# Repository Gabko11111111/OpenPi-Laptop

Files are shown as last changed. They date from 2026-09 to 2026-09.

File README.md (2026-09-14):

# OpenPi Laptop — v0.3 budget prototype

A Raspberry Pi 5 **4 GB** mini laptop with **64 GB microSD**, a **5-inch HDMI display**, a small wireless keyboard with touchpad, and a custom PETG case. The keyboard is retained with screws accessed from underneath. No magnets. The computer uses wall power; only the intact purchased keyboard has its own factory battery.

**Planning total: EUR 250.00 including allowances for delivery and small parts. This is not a confirmed shopping-cart total. Funding, component fit, display touch input and physical tests are not approved or proven.** See the remaining purchasing checks before submitting or ordering.

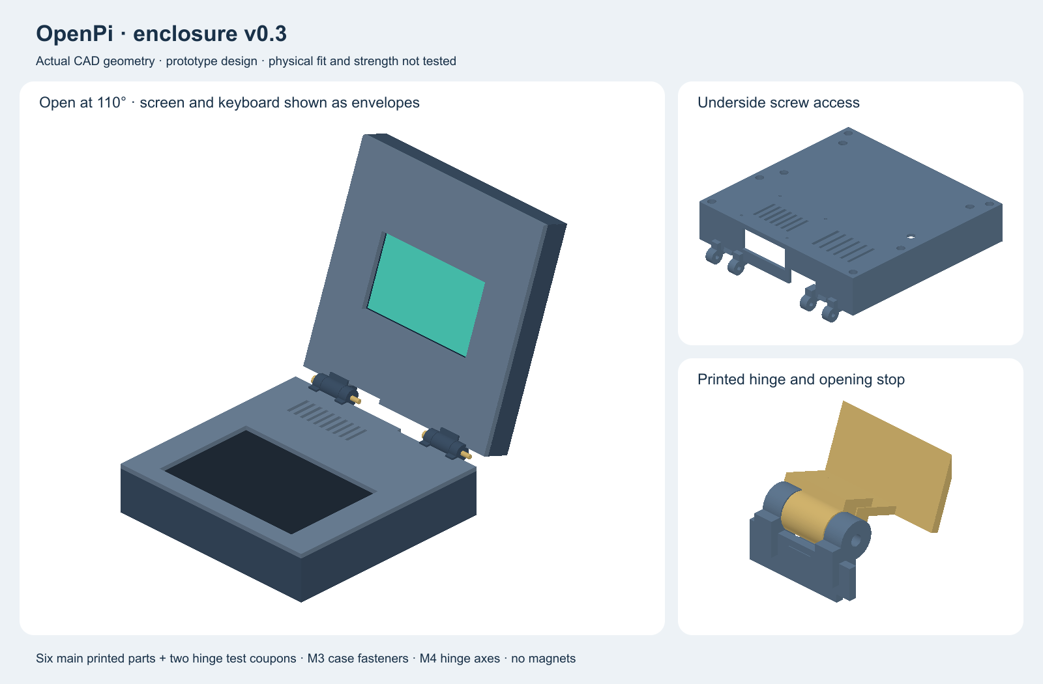
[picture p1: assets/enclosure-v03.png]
Actual v0.3 CAD geometry


The image is rendered from the CAD. Screen and keyboard are simplified reference boxes, not exact product surfaces. The earlier appearance concept and v0.2 assets are historical and are not the current shopping design.

[Stardance project](https://stardance.hackclub.com/projects/61671) · [BOM.csv](BOM.csv) · [Download project ZIP](OpenPi-project-files.zip) · [CAD folder](CAD/v0.3) · [Budget evidence](docs/budget.md)

## What changed to reduce cost

- Keep the requested Pi 5 4 GB, 64 GB storage, proper 27 W power supply and Active Cooler.
- Replace the 7-inch DSI display with the 5-inch HDMI panel, Elecom code 17259. Use the keyboard touchpad; Pi 5 touch drivers are not validated.
- Replace the Perixx keyboard with the small PROLECH/BLOW KS-6 candidate, Pabex code 84-256-. Verify the exact variant and package before ordering.
- Shrink the main case body from 262 × 250 mm to **196 × 190 mm** and resize the keyboard opening, rails, display cradle and bezel. Keep underside screws and printed friction hinges.
- Budget a light-green PETG spool rather than requiring charcoal. Render colors are illustrative.

## Funding and the complete budget

- Target request: **S tier, USD 200 maximum**, subject to reviewer approval.
- Total spending ceiling: **EUR 250**, including delivery, VAT and payment charges.
- At the previously recorded reference rate of EUR 1 = USD 1.1592, USD 200 is approximately EUR 172.53. The expected contribution is approximately **EUR 77.47**, not EUR 50. The builder accepted the EUR 250 plan after this difference was explained.
- These conversion figures are illustrative, not a live grant-card conversion quote. Confirm the actual usable grant and personal contribution before ordering. A lower grant does not authorize a larger personal contribution automatically.
- No grant request or purchase has been submitted by this revision.

## Itemized estimate

| Part | EUR | Evidence |
|---|---:|---|
| Raspberry Pi 5 | 129.90 | Observed retailer price |
| Elecom HDMI LCD code 17259 | 29.99 | Live browser price; 9 in stock |
| PROLECH / BLOW mini KS-6; code 84-256- | 7.39 | Live browser sale price; in stock |
| Goodram M1AA 64 GB | 16.39 | Live browser price; delivery up to 7 days |
| Official Raspberry Pi 27 W USB-C supply | 12.95 | Observed retailer price |
| Official Raspberry Pi 5 Active Cooler | 6.50 | Live browser price; in stock |
| 3DPower Basic PETG Light Green | 13.90 | Search listing reference; live verification pending |
| Enclosure v0.3 fastener set | 10.00 | Unverified purchasing allowance |
| Integral printed hinges | 0.00 | Included elsewhere |
| Display cables | 6.00 | Unverified purchasing allowance |
| Pads and feet | 1.00 | Unverified purchasing allowance |
| USB microSDXC reader | 3.00 | Unverified purchasing allowance |
| Delivery | 12.00 | Unverified combined allowance |
| Reserve | 0.98 | Planning reserve |
| **Planning total** | **250.00** | **Includes estimates; not a delivered quote** |

This replaces the earlier EUR 222 / EUR 50 plan. **No price has been reduced just to match the target:** quoted products and unquoted allowances are labeled separately. The EUR 10 fastener allowance, EUR 12 total delivery allowance and EUR 0.98 reserve are especially tight. Final checkout may exceed this plan; in that case do not buy or submit an inaccurate bill.

## Connections

v0.3 connection overview

The Pi supply powers the computer through USB-C. Video goes from a Pi micro-HDMI port to the display HDMI input. A separate USB lead powers the display through its verified power input; confirm that connector with the seller. The keyboard uses its included wireless USB receiver; its charging cable does not imply USB keyboard data. The cooler uses the Pi fan socket. No laptop battery or DSI ribbon is part of this revision.

## Before ordering

Confirm all package contents, stock, final shipping, cable lengths, display power input and keyboard dimensions. Quote full packs of fasteners and pads. The displayed core prices were checked on 13 September 2026, but the filament quote and all allowances remain unverified. **The plan is not funding-ready until these gaps are resolved.** Basic tools and a card-writing computer must be available or borrowed.

## Step-by-step build

No physical build has been completed. Work in this order; record only your own real work in Lapse and explain AI assistance honestly in Stardance.

1. **Confirm procurement.** Follow the budget checks first. Do not buy the original 7-inch display or Perixx keyboard for this revision. Check all prices including shipping and the actual grant conversion.
2. **Measure the parts.** Record the keyboard body, sturdy outer lip, keys, touchpad, charging port, power switch and battery-cover access. Record the display PCB, glass, connectors, active area and safe support borders. Adjust CAD before a full print. The current keyboard envelope is only a provisional 146.8 × 97.5 × 19 mm box. Curved corners and buttons are not modeled.
3. **Prepare the card.** On an existing computer, use the official Raspberry Pi Imager to write the current recommended Raspberry Pi OS for Pi 5 to the 64 GB card. Select the correct card carefully: writing erases that card. Keep passwords out of recordings. Safely eject after verification.
4. **Bench-test without the enclosure.** With all power disconnected, fit the official Active Cooler using its instructions, insert the card, connect the display by micro-HDMI-to-HDMI cable, connect its verified 5 V USB power input, and insert the keyboard USB receiver. Keep boards on an insulating surface. Charge the keyboard using its factory lead and manual. Connect the official 27 W supply to the Pi last.
5. **Check basic operation.** Confirm boot, HDMI image at the supported 800 × 480 mode, typing, pointer movement and cooling. If the display has no image, test the Pi with a known monitor and consult current official Raspberry Pi display configuration documentation. Do not run old vendor driver scripts blindly. Touchscreen operation is not promised; the keyboard touchpad is the intended pointer.
6. **Power off properly.** Shut down the operating system, wait for shutdown, then disconnect wall power before moving connectors or installing screws.
7. **Print tests first.** Print both hinge coupons and small fit sections of the keyboard opening and display cradle. Check all screws and nut pockets. Update the nominal model until real parts fit without bending.
8. **Slice all parts.** Use calibrated PETG settings, initially 0.2 mm layers and four walls, with solid local hinge reinforcement. Check support removal and the total filament mass including coupons. Keep the full purchase and print plan within the budget.
9. **Assemble.** Follow the exact screw list and detailed assembly document below. Protect display PCB and glass with nonconductive supports. Retain the keyboard from underneath without crushing its factory battery. Keep charging and power controls accessible.
10. **Route cables.** Use separate HDMI and USB power leads with gentle service loops. Keep them out of the fan and hinge teeth. Never power the display from two sources simultaneously. No DSI ribbon is used in v0.3.
11. **Test the finished prototype.** Check boot, keyboard, pointer, fan clearance and thermal throttling under a modest workload. Slowly open and close the lid while watching cables. Record actual results, photos and any failed tests. Do not claim unperformed tests.
12. **Document and submit.** Update the BOM with final quoted prices, keep real devlogs, and let Stardance assess the appropriate tier. No tier or grant is guaranteed. A design request is not proof that the laptop is already built.

[Exact assembly and fasteners](CAD/v0.3/ASSEMBLY.md) · [Budget](docs/budget.md) · [Raspberry Pi documentation](https://www.raspberrypi.com/documentation/computers/getting-started.html)

## CAD downloads

- [Editable assembly](CAD/v0.3/openpi-assembly.FCStd) and [editable parts](CAD/v0.3/openpi-parts.FCStd).
- [Assembly STEP](CAD/v0.3/openpi-assembly.step) and [parts STEP](CAD/v0.3/openpi-parts.step).
- [CAD generator](CAD/build_enclosure.py) and [geometry check results](CAD/v0.3/checks.json).
- [base](CAD/v0.3/STL/base.stl).
- [keyboard_deck](CAD/v0.3/STL/keyboard_deck.stl).
- [keyboard_rail_left](CAD/v0.3/STL/keyboard_rail_left.stl).
- [keyboard_rail_right](CAD/v0.3/STL/keyboard_rail_right.stl).
- [lid_back](CAD/v0.3/STL/lid_back.stl).
- [display_bezel](CAD/v0.3/STL/display_bezel.stl).
- [hinge_fixed_coupon](CAD/v0.3/STL/hinge_fixed_coupon.stl).
- [hinge_moving_coupon](CAD/v0.3/STL/hinge_moving_coupon.stl).

## Full assembly instructions and exact screws

This is a designed prototype with printable geometry. Its fit, strength, hinge friction, and cable life have not been physically verified. Start with the two hinge coupons, not a complete case print.

## Files and dimensions

- `openpi-assembly.FCStd`: assembled model with the lid open at 110 degrees. Keyboard, Pi board, and screen objects are simplified reference envelopes.
- `openpi-parts.FCStd`: six individual manufactured parts in design coordinates.
- `openpi-assembly.step` and `openpi-parts.step`: neutral CAD exports.
- `STL/`: six main printable parts, one fixed hinge coupon, and one moving hinge coupon. Each STL is translated to its own origin; these are not prearranged slicer plates.
- `../build_enclosure.py`: editable parameterized geometry source; regenerate using FreeCAD 1.1.1 Python.
- `checks.json`: recorded geometric and mesh checks.

The base body is 196 × 190 mm; its integral hinge barrels extend depth to 202 mm. The lid back is 196 × 206 mm including its moving hinge tabs. The main base/deck top is 43 mm high. The closed lid is separated from it by 3 mm, and the back of the lid is at 73 mm. Hinge axes are at y=195, z=44.5 in base coordinates. Small added foot pads are outside these dimensions.

The parts fit inside the stated QIDI Q2 270 × 270 × 256 mm volume as geometric envelopes. The deepest part is 206 mm, leaving room for a reasonable brim on a 270 mm bed. Any brim, support, skirt, or printer exclusion must fit too. Check this in the slicer; do not assume the printer can use every nominal millimetre.

## Exact screw shopping list for this revision

All lengths below are measured **under the head**, except nuts and spacers. Choose metric machine screws, not wood screws or self-tapping screws. Stainless A2 is suitable. The counts are quantities actually used; optional spares are separate.

| Item | Used | Application |
|---|---:|---|
| **M3 × 12 mm**, 0.5 mm pitch, ISO 4762 / DIN 912 socket-head screw | **12** | 6 base-to-deck joints + 6 lid-back-to-bezel joints |
| **M3 × 8 mm**, 0.5 mm pitch, ISO 4762 / DIN 912 socket-head screw | **4** | 2 screws per keyboard support rail, accessed from the underside |
| **M4 × 45 mm**, 0.7 mm pitch, ISO 4762 / DIN 912 socket-head screw | **2** | One metal axis per printed hinge |
| **M2.5 × 6 mm**, 0.45 mm pitch, ISO 4762 / DIN 912 socket-head screw | **4** | Through base floor into bottom of Pi spacers |
| **M2.5 × 5 mm**, 0.45 mm pitch, ISO 4762 / DIN 912 socket-head screw | **4** | Through Pi board and washer into top of spacers |
| **M3 hex nut**, DIN 934, 5.5 mm across flats, nominal 2.4 mm high | **16** | 12 shell joints + 4 keyboard-post pockets |
| **M4 nylon-insert locknut**, DIN 985, 7 mm across flats, nominal 5 mm high | **2** | Hinge friction adjustment and axis retention |
| **M3 flat washer**, 3.2 mm ID × 7 mm OD × 0.5 mm | **16** | Under every M3 screw head |
| **M4 flat washer**, 4.3 mm ID × 9 mm OD × 0.8 mm | **4** | Outside the two hinge forks |
| **Fibre friction washer**, 4.3 mm ID × 10 mm OD × 0.5 mm | **4** | Two per hinge, between printed knuckles |
| **M2.5 nylon flat washer**, 2.7 mm ID × 6 mm OD × 0.5 mm | **8** | Four under board screws, four under floor screw heads |
| **M2.5 female–female nylon spacer, 6 mm long**, continuous through-thread, max 5 mm across flats | **4** | Pi mounting, 6 mm above the 3 mm floor |

Total: **26 screws, 18 nuts, 32 washers, 4 spacers**. Suggested spares: two of each screw size, two M3 nuts, and two M3 washers. Spares are not included in the installed counts. Do not substitute a blind-thread spacer: the opposing screw ends require the specified continuous thread.

Tools: 2 mm, 2.5 mm, and 3 mm hex keys; 7 mm spanner for M4 locknuts; calipers; deburring tool. The built-in cooler uses its supplied fasteners. Display package screws are not required by this cradle design; do not drive any new screw into the glass, display PCB, or keyboard.

## Screw-length checks built into the design

| Joint | Designed stack and tip clearance |
|---|---|
| Base/deck M3 × 12 | Driver-well shoulder z=30.5; 0.5 mm washer places under-head plane z=30. Tip z=42. Nut seated at z=39.2–41.6; blind bore ends z=42.5; deck top z=43. |
| Lid/bezel M3 × 12 | Shoulder z=13.5; washer gives under-head plane z=13. Tip z=25. Nut z=22.2–24.6; bore ends z=26; front z=27. |
| Keyboard M3 × 8 | Rail bottom z=16; washer gives under-head plane z=15.5. Tip z=23.5. Nut z=19.2–21.6; bore ends z=24.5. Screw axes lie outside the keyboard envelope. |
| Pi M2.5 × 6 and × 5 | Bottom screw engages 2.5 mm above the floor. Top screw engages about 2.9 mm assuming 1.6 mm PCB + 0.5 mm washer. Opposing tips have nominal 0.6 mm clearance. Verify actual thickness and spacer thread before tightening. |
| Hinge M4 × 45 | 36 mm knuckle/inner-washer stack + 1.6 mm outer washers + 5 mm nut = 42.6 mm. A 45 mm screw projects nominally 2.4 mm beyond the nut. Confirm the thread reaches the nylon ring; do not replace with a 40 mm screw. |

These are nominal geometric stacks, not manufacturing-tolerance guarantees. Nut-pocket AF is 5.8 mm; M3 clearance bores are 3.4 mm; hinge bores are 4.4 mm; driver wells are 8.2 mm. Printed holes may need careful deburring. If a screw bottoms before clamping, stop and correct the fit.

## Keyboard retention

1. Print the deck and rails only after measuring the exact keyboard's plastic rim, keys, and cable exit. The current envelope is 146.8 × 97.5 × 19 mm, positioned x=24.6–171.4, y=14–111.5, z=20–39. The top opening is 142.8 × 93.5 mm and assumes a usable 2 mm peripheral housing lip. Confirm that this lip does not cover keys or touchpad controls.
2. Fit the four M3 nuts into the underside post pockets. Fit the six shell-joint nuts into the underside deck pockets. A small piece of tape can temporarily retain nuts; keep adhesive off threads.
3. Insert the intact keyboard from below. Attach 1 mm soft pad strips only under its sturdy outer housing edges, above the two rails. Keep pads clear of electronics and moving controls.
4. Attach the two rails using four M3 × 8 screws and washers. The rails touch post shoulders at z=19: this is a hard tightening stop. Tighten gently until seated, never until the keyboard housing bends.
5. A thinner keyboard needs measured rigid shims under its rim, not extreme screw tightening or a large soft foam stack. The current envelope is a provisional KS-6 sizing assumption, not a measurement of the purchased unit; update support height and lip after measuring its rim. Keycap height alone is not sufficient.
6. With the base installed, the four rail screws remain accessible through underside driver holes. Removing the keyboard requires undoing the base/deck fasteners and rails, then withdrawing it from below. It does not lift out from the top.

## Pi and cable assembly

1. With power disconnected, install four 6 mm nylon spacers using the four M2.5 × 6 floor screws and nylon washers.
2. Place the Pi on the spacers, USB/Ethernet edge toward the left service opening, USB-C edge toward the rear opening. Use the four M2.5 × 5 top screws and nylon washers. Stop if the washer contacts a component rather than the board's mounting land.
3. The hole pitch is 58 × 49 mm, based on the [Pi 5 reference drawing](https://datasheets.raspberrypi.com/rpi5/raspberry-pi-5-mechanical-drawing.pdf). The manufacturer itself requires physical-component verification before production. The cooler and all plugged-in cable envelopes still need a physical clearance check.
4. Plug the wireless receiver into USB-A and leave the keyboard charging socket and power switch accessible. Retain the intact keyboard and its factory battery; do not wire its battery to the Pi. Use its included charging lead according to its manual. The generous service openings are intentional prototype features; verify plug insertion before refining them.
5. Route the micro-HDMI/HDMI video cable and USB display power cable through the central rear openings in both shells. Use soft edge protection and strain relief, leaving a service loop. Cables are not included in the rigid-body collision simulation.

## Lid and hinges

1. Test the **fixed and moving hinge coupons** first with one M4 × 45 screw, two outer steel washers, two inner fibre washers, and one M4 locknut. These coupons reproduce the real geometry.
2. Install display support pads against sturdy rear structural surfaces, avoiding electronics and ribbon connectors. The CAD reserves a 120 × 75 × 16 mm display envelope at z=4–20. The seller lists an 8 mm body; connector protrusions and pad stack are unverified. Use measured nonconductive supports under structural borders, not exposed solder joints. Confirm the physical module and its connector protrusions before closing the lid.
3. The bezel opening is 112 × 64 mm, based on a provisional centered 110.7 × 62.3 mm viewing area. Centering is assumed; check the actual active-area location. Never load the active glass or force a bowed panel into position.
4. Fit six M3 nuts to bezel pockets. Attach bezel to lid back with six M3 × 12 screws and washers from the rear. Printed columns limit closure; the padding should retain the display without bending it. Change pad thickness or CAD if the module stack differs.
5. Assemble each hinge along the axis in this order: **M4 screw head → steel washer → fixed knuckle → fibre washer → moving knuckle → fibre washer → fixed knuckle → steel washer → M4 locknut**.
6. Tighten the locknut only enough to remove play and obtain modest friction. The printed stops meet at 110 degrees. Do not force the lid beyond the stop. PETG may creep under sustained clamp load; holding torque and durability require real tests. No numerical tightening torque is claimed.
7. Attach the deck/base with six M3 × 12 screws and washers through the deep underside wells. Apply four feet at least 4 mm thick so the Pi floor screw heads clear the table; keep feet away from vents.
8. Slowly open and close the unpowered lid while watching the cables. Then test the electronics and record results using the build guide. The 110-degree stop is not proof of cable suitability or long-term strength.

## Printing order

1. Print the two hinge coupons first, using PETG, and check the 4.4 mm axis bore and 0.5 mm washer gaps.
2. Check nut capture, rail fit, keyboard lip, display thickness, and the actual board against the design before printing all six large parts. Make local test cuts of those regions in the slicer if needed.
3. Base: floor on bed; use local supports for hinge overhangs, with access for removal. Lid back: outer back on bed; support hinge overhangs. Deck: rotate so its flat top is on the bed and posts grow upward. Bezel: front face on bed. Rails: broad face on bed.
4. Start with a calibrated PETG profile, 0.2 mm layers and at least four perimeters; use solid local infill around hinge roots. These are starting settings, not a strength certification. Inspect layer bonding and hinge-axis alignment on the coupons.
5. Check slicer bounds before adding a brim. The lid is 206 mm deep. Verify brim, skirt and supports in the slicer.

## Automated checks completed

Six main parts exported as valid single solids and closed STL meshes. Bounding boxes fit the nominal printer volume. Named static printed parts and the simplified Pi/keyboard envelopes do not intersect. The rigid printed lid has no detected intersection at the eleven sampled positions from 0 to 110 degrees; a 112-degree check contacts the stop. The test samples angles; it is not a continuous-motion or finite-element analysis. Physical assembly, clamp pressure, cable movement, thermals, and hinge life remain untested.

## Budget and readiness

This is the EUR 250 planning revision. The same exact screw list is retained, with an unquoted EUR 10 purchasing allowance. No physical fit is certified. Display touch input is not part of the validated plan: use HDMI video and the keyboard touchpad. Seller confirmation of display power and keyboard dimensions is required before purchase or full printing.

## AI assistance and honest status

ChatGPT/Codex helped with sourcing, budgeting, documentation, the earlier concept image, parametric CAD and uploads. The builder must understand, measure, adapt, print, assemble and test the hardware. No recorded AI execution time is being presented as the builder's manual work. CAD checks are not physical test results.

## Historical revisions

[The previous BOM](docs/archive/BOM-v02.csv) documents the EUR 371.59 selection. [v0.2 CAD](CAD/v0.2) is preserved for reference and is incompatible with this budget selection. Use v0.3 for current fit experiments. Do not mix revision parts.

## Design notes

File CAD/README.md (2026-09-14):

# OpenPi CAD

Current revision: **v0.3 budget prototype**. Main body 196 × 190 mm, nominal 5-inch HDMI display and small KS-6 keyboard envelopes. Exact purchased component fit is not verified.

- [Assembly and exact fasteners](v0.3/ASSEMBLY.md)
- [Assembly model](v0.3/openpi-assembly.FCStd)
- [Printable parts](v0.3/STL)
- [Validation](v0.3/checks.json)

Run `build_enclosure.py` with FreeCAD Python to regenerate v0.3. The old v0.2 model remains in `v0.2`; its source is `build_enclosure_v02.py`. The original layout files are historical. Do not mix revisions.

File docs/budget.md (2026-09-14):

# OpenPi v0.3 budget — EUR 250 ceiling

Updated 14 September 2026 using the 13 September price checks. **This is a revised planning BOM, not a verified checkout quotation or a funding-ready guarantee.** A total of EUR 250 is achieved by selecting a smaller HDMI screen and a small wireless keyboard, and assigning the remaining unquoted costs explicit allowances. Do not treat allowances as purchased or confirmed offers.

## Funding

- Target request: **S tier, USD 200 maximum**, subject to reviewer approval.
- Total spending ceiling: **EUR 250**, including delivery, VAT and payment charges.
- At the previously recorded reference rate of EUR 1 = USD 1.1592, USD 200 is approximately EUR 172.53. The expected contribution is approximately **EUR 77.47**, not EUR 50. The builder accepted the EUR 250 plan after this difference was explained.
- These conversion figures are illustrative, not a live grant-card conversion quote. Confirm the actual usable grant and personal contribution before ordering. A lower grant does not authorize a larger personal contribution automatically.
- No grant request or purchase has been submitted by this revision.

## Itemized estimate

| Part | EUR | Evidence |
|---|---:|---|
| Raspberry Pi 5 | 129.90 | Observed retailer price |
| Elecom HDMI LCD code 17259 | 29.99 | Live browser price; 9 in stock |
| PROLECH / BLOW mini KS-6; code 84-256- | 7.39 | Live browser sale price; in stock |
| Goodram M1AA 64 GB | 16.39 | Live browser price; delivery up to 7 days |
| Official Raspberry Pi 27 W USB-C supply | 12.95 | Observed retailer price |
| Official Raspberry Pi 5 Active Cooler | 6.50 | Live browser price; in stock |
| 3DPower Basic PETG Light Green | 13.90 | Search listing reference; live verification pending |
| Enclosure v0.3 fastener set | 10.00 | Unverified purchasing allowance |
| Integral printed hinges | 0.00 | Included elsewhere |
| Display cables | 6.00 | Unverified purchasing allowance |
| Pads and feet | 1.00 | Unverified purchasing allowance |
| USB microSDXC reader | 3.00 | Unverified purchasing allowance |
| Delivery | 12.00 | Unverified combined allowance |
| Reserve | 0.98 | Planning reserve |
| **Planning total** | **250.00** | **Includes estimates; not a delivered quote** |

## Evidence and changes

The Pi 5 **4 GB** and **64 GB storage** remain. The official 7-inch DSI screen is replaced by Elecom code **17259**, a **5-inch 800 × 480 HDMI** panel. Treat it as a video display controlled through the keyboard's touchpad: its old XPT2046 touch software is not validated for Pi 5. The seller image shows a separate small USB power connector; confirm the delivered board uses micro-USB 5 V power before buying cables. A rigid Pi 3 HDMI adapter is not suitable for the Pi 5 connector spacing.

The Perixx wired keyboard is replaced by Pabex code **84-256-**, a PROLECH/BLOW mini KS-6 candidate. Its live price was EUR 7.39. Confirm exact model, included USB receiver, battery, charging cable, Linux input operation and physical housing/rim dimensions. USB charging must not be described as wired keyboard data. Its factory battery powers only the keyboard; the computer remains wall-powered.

The new case is v0.3 with a **196 × 190 mm main body**, underside retention and printed hinges. It is not the old v0.2 case with a changed price label. The CAD uses nominal unmeasured keyboard and display envelopes; physical retention, power-switch access and cable bends remain to verify.

## Source links

- [Raspberry Pi 5](https://www.elecom.sk/raspberry-pi-5-4-gb-2/): EUR 129.90; Observed retailer price.
- [Elecom HDMI LCD code 17259](https://www.elecom.sk/5-0-palcovy-dotykovy-lcd-displej-hdmi-800x480-pre-raspberry-pi-3b--xpt2046-rezistivny/): EUR 29.99; Live browser price; 9 in stock.
- [PROLECH / BLOW mini KS-6; code 84-256-](https://www.pabex.sk/bezdrotova-klavesnica-s-touchpadom-84-256-/): EUR 7.39; Live browser sale price; in stock.
- [Goodram M1AA 64 GB](https://www.pabex.sk/pamatova-karta-64gb-tgd-m1aa0640r12/): EUR 16.39; Live browser price; delivery up to 7 days.
- [Official Raspberry Pi 27 W USB-C supply](https://www.elecom.sk/raspberry-pi-27w-usb-c-napajaci-zdroj--eu--biely-2/): EUR 12.95; Observed retailer price.
- [Official Raspberry Pi 5 Active Cooler](https://www.elecom.sk/raspberry-pi-5-active-cooler-2/): EUR 6.50; Live browser price; in stock.
- [3DPower Basic PETG Light Green](https://www.filamenthouse.sk/p/3dpower-basic-petg-svetlozelena-light-green-1kg): EUR 13.90; Search listing reference; live verification pending.

## Mandatory checks before ordering or submitting

1. Obtain a combined delivered quotation for the exact selections. The **EUR 12 shipping allowance is not confirmed** across all stores.
2. Quote the full packs needed for all fasteners, pads, reader and both display cables. Do not count only the fraction used if a larger pack must be purchased. The EUR 10 fastener allowance may prove insufficient.
3. Verify filament stock and price directly: EUR 13.90 is a search-listing reference, not a completed live store check. The older EUR 12.30 transition-filament offer was unavailable and is not used.
4. Slice the case, coupons and supports. One 1 kg spool is budgeted. Main CAD solid volume is approximately 629 cm³, equivalent to approximately 799 g at 1.27 g/cm³ if fully solid; this is not a slicer prediction and excludes supports and mistakes. Keep all printing within the spool or find savings for more material.
5. Confirm display power and the real keyboard variant before printing. Do not install old vendor OS images on the Pi 5 to force touch support; HDMI video plus the keyboard touchpad is the baseline.
6. Only proceed if the final total including fees is at most EUR 250 and the actual grant/personal split is accepted. There is only EUR 0.98 of reserve, so the estimate is fragile.

The previous EUR 371.59 selection and its evidence are retained in `archive/BOM-v02.csv` and `archive/budget-v02.md`. The old EUR 222 ceiling/EUR 50 contribution are superseded by this accepted EUR 250 plan. Basic tools and a computer for writing the card must be available or borrowed; buying tools is not covered.

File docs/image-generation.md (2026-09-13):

# Concept illustration provenance

The cover image in `assets/openpi-concept.png` was generated with the built-in ImageGen tool, in generation mode, on 2026-09-13. It is an appearance concept, not a photograph, dimensioned drawing, or proof of a completed build. Mechanical layout files take precedence over the illustration. The screen proportions in the illustration are approximate.

The project owner specified a Raspberry Pi 5 with 4 GB RAM, a 64 GB microSD card, a keyboard with a touchpad, and retention screws accessible from below. There are no magnets. AI assistance was used for the concept illustration and documentation. Actual construction, measurements, and testing remain to be done and recorded separately.

The exact generation prompt is saved in [image-prompt.txt](image-prompt.txt). Final image: [openpi-concept.png](../assets/openpi-concept.png).

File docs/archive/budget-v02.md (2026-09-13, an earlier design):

# Budget review — 13 September 2026

**Result: the selected new-parts build does not fit the S-tier allowance. This is a transparent planning estimate, not a funding-ready shopping cart.** No order has been placed. The personal contribution is capped at EUR 50; the procurement target is EUR 222 including delivery and fees. The current selection does not meet that target.

## New funding constraint

Target: S tier, request at most USD 200, subject to approval. Total delivered cost ceiling: EUR 222. Personal contribution ceiling: EUR 50. These are limits, not verified prices. The actual grant conversion and fees determine whether the full EUR 222 can be afforded. A cheaper compatible BOM and revised CAD remain necessary; the existing BOM is retained as the v0.2 cost evidence, not relabelled with invented prices.

## Cost summary

| Group | EUR |
|---|---:|
| Raspberry Pi 5, 4 GB | 129.90 |
| Official 7-inch Touch Display 2 | 64.50 |
| Perixx keyboard with touchpad, reference variant | 39.99 |
| SanDisk Ultra 64 GB | 19.90 |
| Official 27 W supply, cable included | 12.40 |
| Official Active Cooler | 5.90 |
| **Electronics subtotal** | **272.59** |
| PETG, full 1 kg spool allowance | 25.00 |
| v0.2 fasteners, hinge axes, washers and standoffs allowance | 20.00 |
| Integral printed hinges | 0.00 extra; included in filament |
| Additional display cable/power lead allowance | 10.00 |
| Pads, feet, and strain relief allowance | 4.00 |
| USB microSD reader allowance | 5.00 |
| Shipping and destination-tax adjustment allowance | 20.00 |
| Contingency | 15.00 |
| **Planning total** | **371.59** |

The [ECB reference rate for 11 September 2026](https://www.ecb.europa.eu/stats/policy_and_exchange_rates/euro_reference_exchange_rates/html/index.en.html) was **1 EUR = 1.1592 USD**. On that reference basis:

- EUR 371.59 × 1.1592 = **USD 430.75**.
- The [S-tier cap of USD 200](https://stardance.hackclub.com/resources/tiers) corresponds to approximately **EUR 172.53**.
- Estimated gap: **USD 230.75**, or about **EUR 199.06**. Actual payment conversion and fees may differ.

Even the Pi and selected display alone total **EUR 194.40**, approximately **USD 225.35**, before storage, input, power, printing, or delivery. This rules out funding this exact all-new selection solely with USD 200 at these quotes. It does not prove that no cheaper used-parts design could exist.

## Price evidence and limitations

| Item | Evidence | Qualification |
|---|---|---|
| Pi 5 / 4 GB | [Elecom](https://www.elecom.sk/raspberry-pi-5-4-gb-2/): EUR 129.90 | Retail reference, not a locked delivered quote |
| Cheaper Pi listing checked | [BerryBase](https://www.berrybase.de/raspberry-pi-5-4gb-ram): EUR 118.50 | Unavailable when checked; excluded from purchase estimate |
| Display | [BerryBase](https://www.berrybase.de/raspberry-pi-touch-display-2?c=320): EUR 64.50 | 7-inch model, stock shown when checked |
| Keyboard | [Perixx](https://eu.perixx.com/products/periboard-510h): EUR 39.99 | Page selected Spanish; English US is the desired variant, with its price/stock still to confirm |
| Card | [BerryBase microSD listing](https://www.berrybase.de/multimedia-office/speicherkarten-usb-sticks/microsd-karten): EUR 19.90 | SanDisk Ultra 64 GB, EAN 619659200541 |
| Supply | [BerryBase](https://www.berrybase.de/detail/019234a5bfb57193899acec14a1eebd6): EUR 12.40 | Official 27 W EU model; cable included |
| Cooler | [BerryBase](https://www.berrybase.de/raspberry-pi-active-cooler-luefter-fuer-raspberry-pi-5): EUR 5.90 | Official Pi 5 Active Cooler |

Displayed prices include the seller's stated VAT. Delivery to Slovakia, destination VAT, availability, keyboard variants, and payment fees must be rechecked at checkout. The estimate is not a claim to be the cheapest possible selection. Small hardware and material amounts are explicitly **allowances**, not sourced offers.

The additional ribbon allowance is separate from the display's included bench cable. There is no separate HDMI cable, USB-C cable, battery, mouse, or paid operating system in this budget. Only the printer is confirmed owned. A computer for card writing and basic tools must be available or borrowed; purchasing tools is not covered by this estimate.

Enclosure revision v0.2 replaces bought hinges with integral printed hinges and two M4 axes. The former EUR 8 fastener and EUR 12 hinge allowances are combined into a EUR 20 hardware allowance; the total estimate is unchanged. Exact installed fasteners are listed in README and CAD/v0.2/ASSEMBLY.md. This is not a verified hardware-kit price, and optional spares are not included. Recheck filament usage after slicing the larger enclosure.

## What would make USD 200 feasible?

This remains an unresolved procurement/design task. It requires confirmed lower delivered prices or supplied components, and probably a cheaper display and input arrangement. Used or donated parts must be genuinely available and acceptable under the funding rules; none are assumed here. Replacing the display or keyboard also requires updating the enclosure, wiring, and tests.

The requested Pi 5 **4 GB** and **64 GB** storage have been preserved. Silently substituting a Pi 4, a 2 GB board, or a 32 GB card would not meet the stated requirements. Simply labeling a larger bill “S tier” also does not solve the shortfall. A higher tier requires the corresponding project merit and review, not merely a higher price.

Before submission, replace every allowance with an actual part/quantity and delivered quote, resolve the keyboard variant, verify the total in USD including fees, and document how any remaining difference is funded. The builder has authorized a personal contribution of at most EUR 50. Do not order if the actual usable grant plus EUR 50 cannot cover all costs.

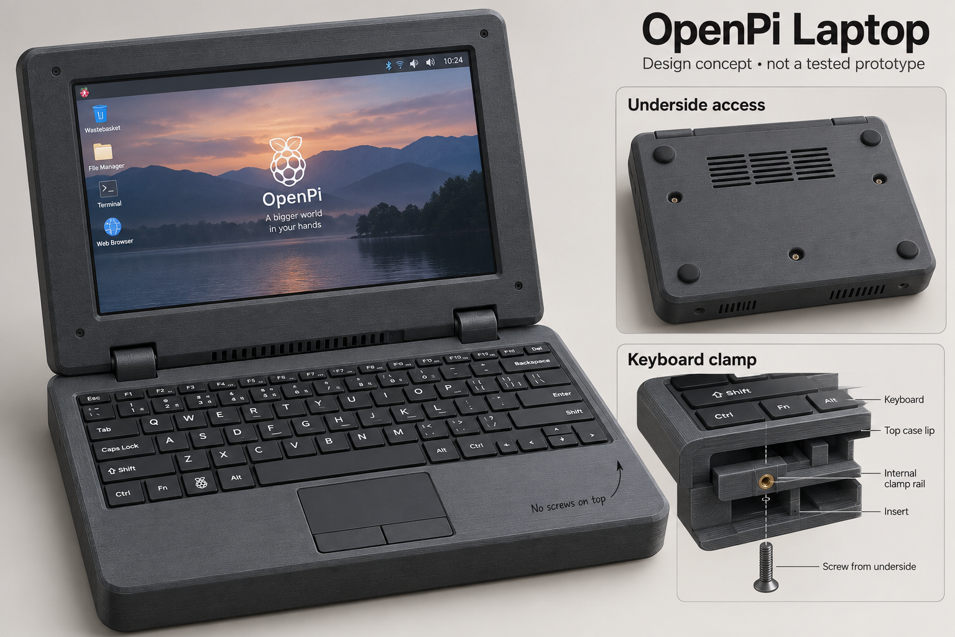
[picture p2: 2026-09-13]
assets/openpi-concept.png

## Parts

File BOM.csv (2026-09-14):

Category | Part | Specification | Quantity | Unit_EUR | Line_EUR | Price_status | Source_URL | Notes | Checked_date
Computer | Raspberry Pi 5 | 4 GB RAM | 1 | 129.90 | 129.90 | Observed retailer price | https://www.elecom.sk/raspberry-pi-5-4-gb-2/ | Recheck stock and checkout; no weaker RAM variant | 2026-09-13
Display | Elecom HDMI LCD code 17259 | 5 inch; 800 x 480; XPT2046 board; HDMI video | 1 | 29.99 | 29.99 | Live browser price; 9 in stock | https://www.elecom.sk/5-0-palcovy-dotykovy-lcd-displej-hdmi-800x480-pre-raspberry-pi-3b--xpt2046-rezistivny/ | Use HDMI video and keyboard touchpad; Pi 5 touchscreen driver NOT validated; verify micro-USB power port before order | 2026-09-13
Input | PROLECH / BLOW mini KS-6; code 84-256- | Small wireless keyboard with touchpad | 1 | 7.39 | 7.39 | Live browser sale price; in stock | https://www.pabex.sk/bezdrotova-klavesnica-s-touchpadom-84-256-/ | Confirm exact KS-6 variant; USB receiver; battery and charging lead included; housing and rim must be measured | 2026-09-13
Storage | Goodram M1AA 64 GB | 64 GB microSDXC; Class 10 UHS-I; SD adapter | 1 | 16.39 | 16.39 | Live browser price; delivery up to 7 days | https://www.pabex.sk/pamatova-karta-64gb-tgd-m1aa0640r12/ | No A1 claim; seller calls it SDHC but 64 GB is SDXC; adapter is not a USB reader | 2026-09-13
Power | Official Raspberry Pi 27 W USB-C supply | EU plug; 5.1 V / 5 A; captive cable | 1 | 12.95 | 12.95 | Observed retailer price | https://www.elecom.sk/raspberry-pi-27w-usb-c-napajaci-zdroj--eu--biely-2/ | No separate laptop power cable | 2026-09-13
Cooling | Official Raspberry Pi 5 Active Cooler | Dedicated Pi 5 fan connector | 1 | 6.50 | 6.50 | Live browser price; in stock | https://www.elecom.sk/raspberry-pi-5-active-cooler-2/ | Keep supplied push pins and thermal pads | 2026-09-13
Case | 3DPower Basic PETG Light Green | 1.75 mm; one 1 kg spool | 1 | 13.90 | 13.90 | Search listing reference; live verification pending | https://www.filamenthouse.sk/p/3dpower-basic-petg-svetlozelena-light-green-1kg | Not charcoal; recheck stock and price; slice total including supports and coupons below 1 kg | 2026-09-13
Fasteners | Enclosure v0.3 fastener set | 26 screws; 18 nuts; 32 washers; 4 spacers | 1 | 10.00 | 10.00 | Unverified purchasing allowance |  | Exact installed sizes in CAD/v0.3/ASSEMBLY.md; package quantities and delivered cost still need quotation | 2026-09-13
Hinges | Integral printed hinges | 2 printed hinge sets; M4 x 45 metal axes | 2 | 0.00 | 0.00 | Included elsewhere |  | Filament in Case row; metal axes and washers in Fasteners row | 2026-09-13
Cables | Display cables | Micro-HDMI to HDMI cable; USB-A to micro-USB power cable | 1 | 6.00 | 6.00 | Unverified purchasing allowance |  | Confirm board power port; no DSI ribbon; do not use rigid Pi 3 HDMI adapter with Pi 5; route a loose hinge loop | 2026-09-13
Assembly | Pads and feet | Insulating retention pads; four feet at least 4 mm high; strain relief | 1 | 1.00 | 1.00 | Unverified purchasing allowance |  | Full purchase cost must fit; not assuming material is already owned | 2026-09-13
Setup | USB microSDXC reader | USB-A; supports 64 GB cards | 1 | 3.00 | 3.00 | Unverified purchasing allowance |  | Needed to install Raspberry Pi OS unless a compatible reader can be borrowed | 2026-09-13
Delivery | Delivery | Combined shipping and checkout differences to Slovakia | 1 | 12.00 | 12.00 | Unverified combined allowance |  | Not a checkout quote; includes all suppliers and fastener/cable orders; no purchase if exceeded without savings elsewhere | 2026-09-13
Reserve | Reserve | Price or payment-fee reserve | 1 | 0.98 | 0.98 | Planning reserve |  | Very small margin; no guarantee of final delivered cost | 2026-09-13

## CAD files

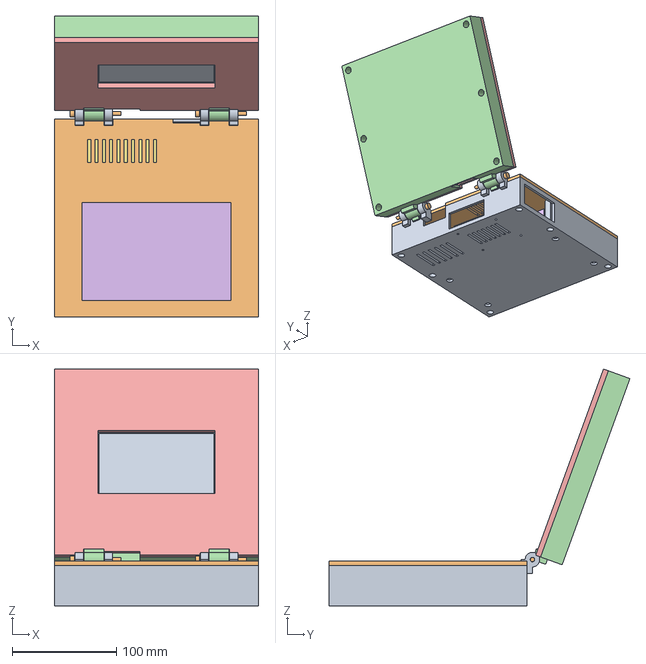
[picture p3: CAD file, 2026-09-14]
CAD/v0.3/openpi-assembly.step
196.0 x 288.5 x 227.2 mm

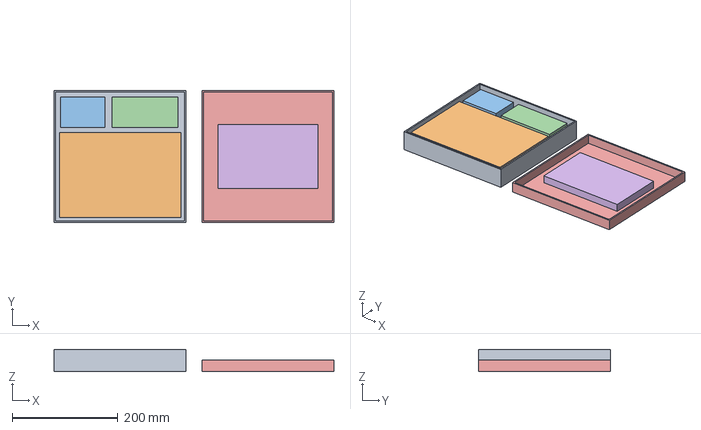
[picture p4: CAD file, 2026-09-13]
CAD/openpi-layout.step
530.0 x 250.0 x 42.0 mm

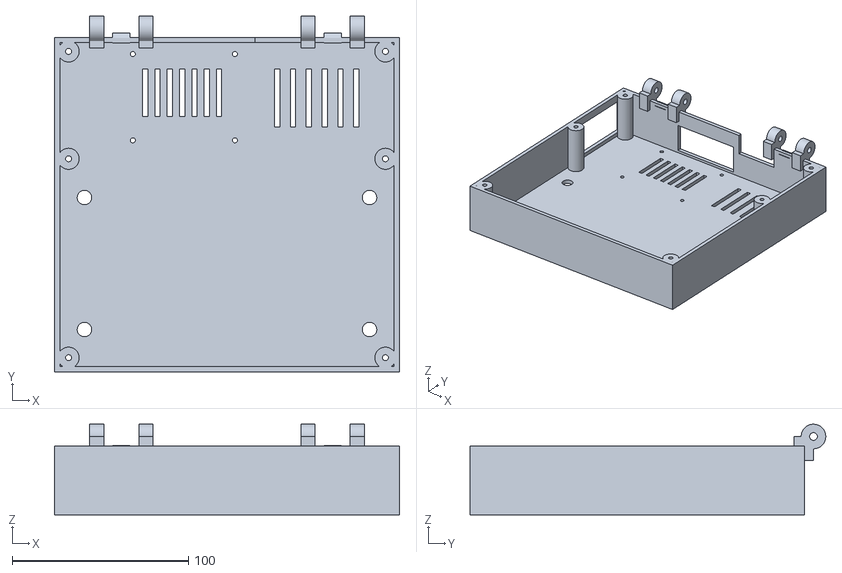
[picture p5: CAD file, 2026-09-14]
CAD/v0.3/STL/base.stl
196.0 x 202.0 x 51.5

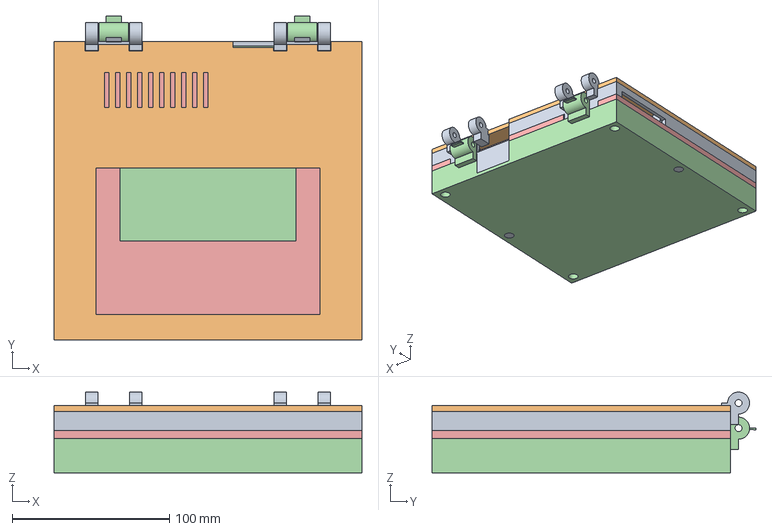
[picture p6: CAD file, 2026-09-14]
CAD/v0.3/openpi-parts.step
196.0 x 206.0 x 51.5 mm

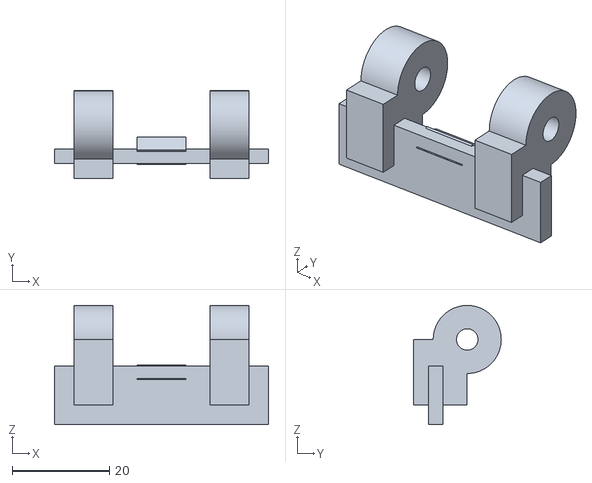
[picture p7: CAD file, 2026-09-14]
CAD/v0.3/STL/hinge_fixed_coupon.stl
44.0 x 18.0 x 24.5

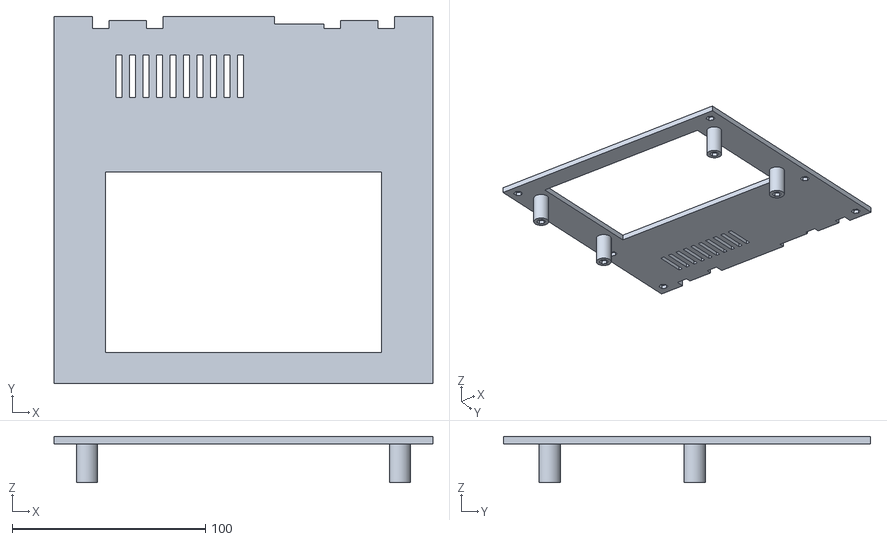
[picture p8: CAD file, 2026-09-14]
CAD/v0.3/STL/keyboard_deck.stl
196.0 x 190.0 x 24.0

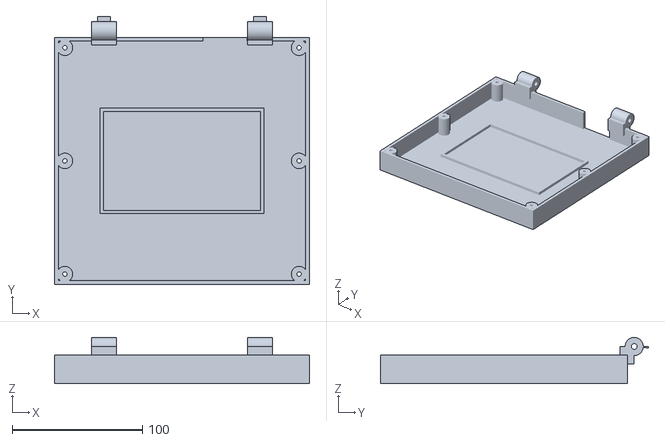
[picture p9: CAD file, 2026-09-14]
CAD/v0.3/STL/lid_back.stl
196.0 x 206.0 x 35.5

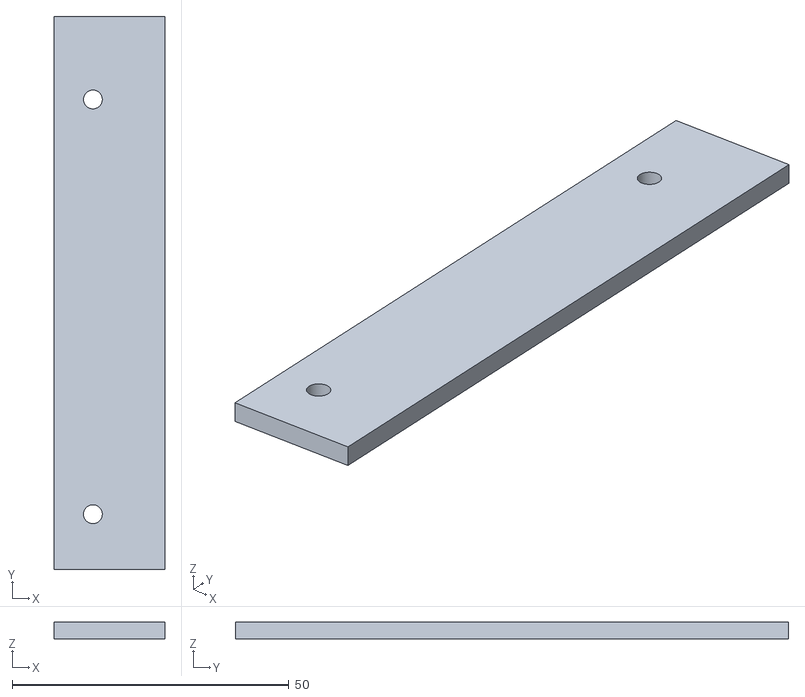
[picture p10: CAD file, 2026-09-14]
CAD/v0.3/STL/keyboard_rail_left.stl
20.0 x 100.0 x 3.00

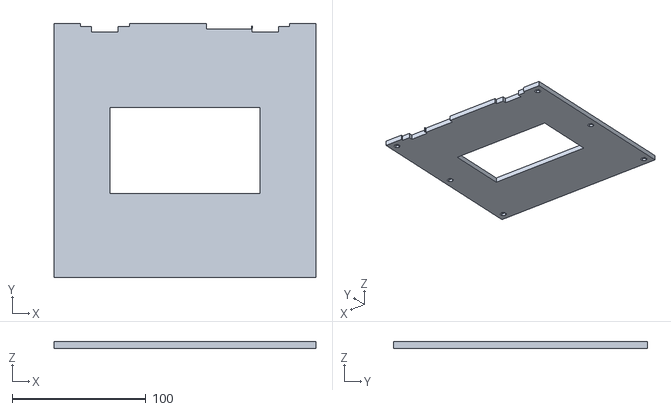
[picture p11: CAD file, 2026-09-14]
CAD/v0.3/STL/display_bezel.stl
196.0 x 190.0 x 5.00

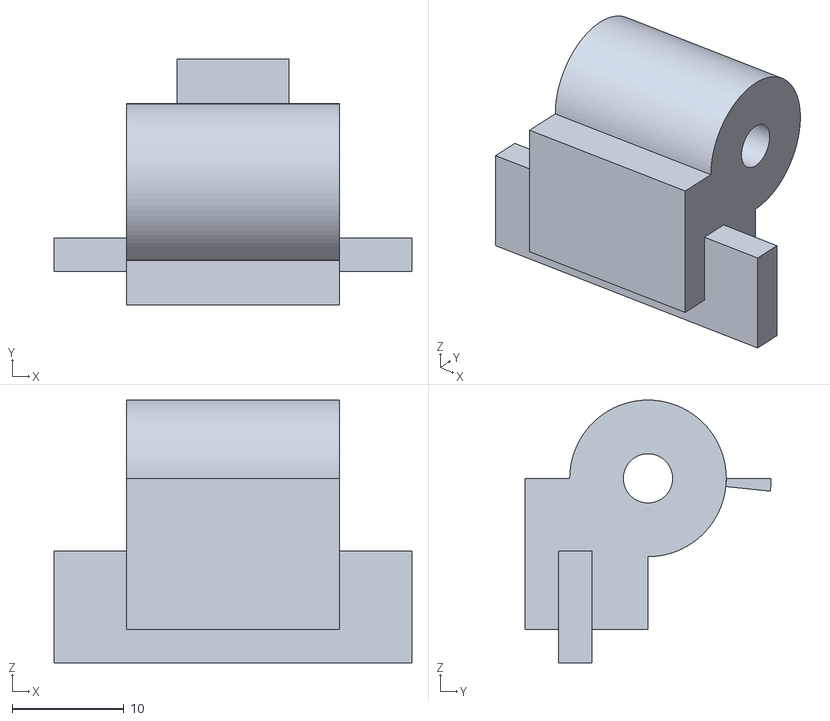
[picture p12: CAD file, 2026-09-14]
CAD/v0.3/STL/hinge_moving_coupon.stl
32.0 x 22.0 x 23.5

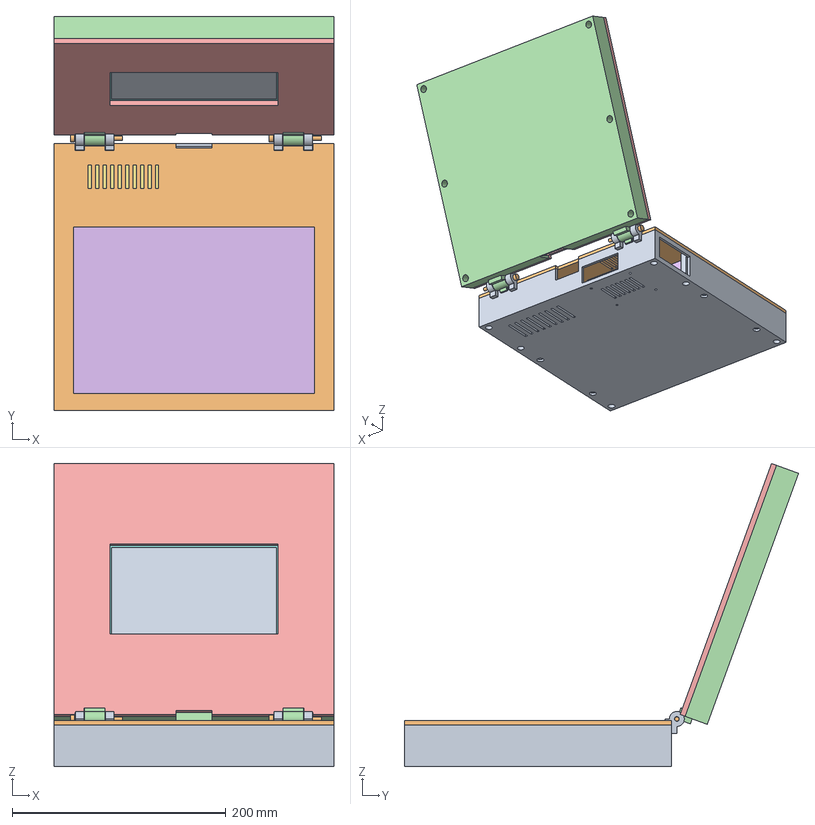
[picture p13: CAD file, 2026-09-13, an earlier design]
CAD/v0.2/openpi-assembly.step
262.0 x 369.0 x 283.6 mm

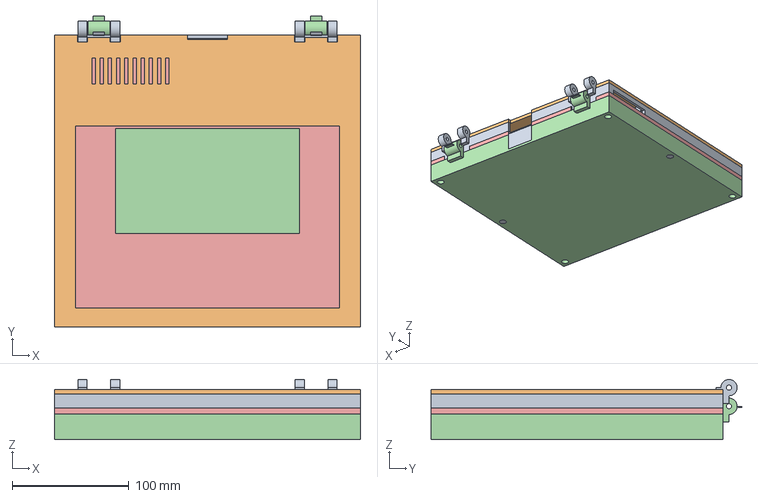
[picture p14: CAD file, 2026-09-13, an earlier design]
CAD/v0.2/openpi-parts.step
262.0 x 266.0 x 51.5 mm

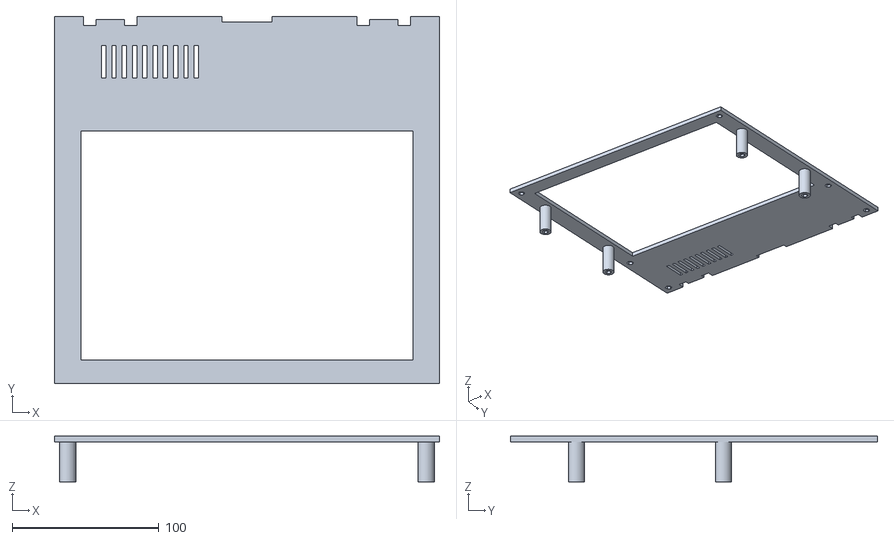
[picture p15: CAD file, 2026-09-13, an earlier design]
CAD/v0.2/STL/keyboard_deck.stl
262.0 x 250.0 x 31.0

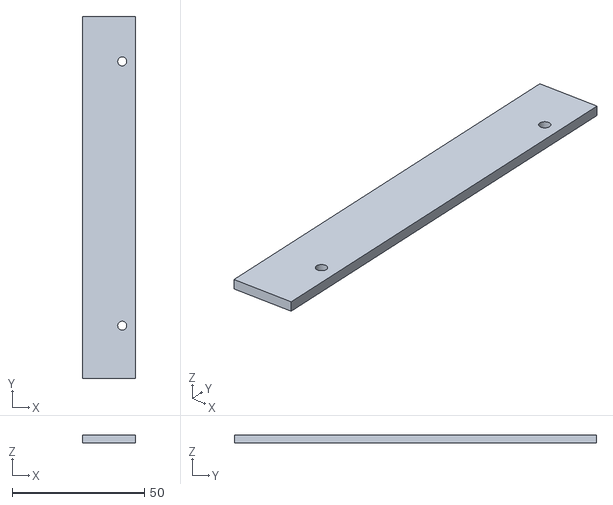
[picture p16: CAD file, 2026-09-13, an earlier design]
CAD/v0.2/STL/keyboard_rail_right.stl
20.0 x 137.0 x 3.00

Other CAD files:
CAD/v0.3/STL/keyboard_rail_right.stl
CAD/v0.2/STL/lid_back.stl
CAD/v0.2/STL/display_bezel.stl
CAD/v0.2/STL/hinge_fixed_coupon.stl
CAD/openpi-layout.FCStd
CAD/v0.2/STL/base.stl
CAD/v0.2/STL/hinge_moving_coupon.stl
CAD/v0.2/STL/keyboard_rail_left.stl
CAD/v0.2/openpi-assembly.FCStd
CAD/v0.2/openpi-parts.FCStd
CAD/v0.3/openpi-assembly.FCStd
CAD/v0.3/openpi-parts.FCStd

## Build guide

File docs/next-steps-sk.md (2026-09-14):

# Čo ďalej — verzia v0.3

Plánovaný rozpočet je 250 €, žiadosť má byť najviac 200 $. Pri skoršom orientačnom kurze by doplatok bol asi 77,47 €. Grant nie je schválený.

1. Najprv potvrď konečné ceny dopravy, skrutiek, káblov, čítačky a filamentu. Súčet 250 € zatiaľ obsahuje odhady.
2. Pred nákupom over konektor napájania displeja a presný model klávesnice. Displej je menší 5-palcový HDMI, nie pôvodný 7-palcový DSI.
3. Zmeraj skutočné súčiastky a uprav 3D model. Najprv vytlač skúšky pántov a uchytenia, nie celý obal.
4. Používaj súbory CAD/v0.3. Obal v0.2 je starý a k novým dielom nepatrí.
5. Žiadosť zatiaľ neodosielaj s neoverenými cenami. Do políčka sumy patrí 200 dolárov, nie 250 eur.

Celý návod a presné skrutky sú v hlavnom README.

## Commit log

2026-09-13 Add OpenPi design images and wiring diagram
2026-09-13 Add printable enclosure parts and hinge test coupons
    [base.stl, display_bezel.stl, hinge_fixed_coupon.stl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]
2026-09-13 Add editable enclosure CAD and assembly instructions
    [openpi-assembly.FCStd, openpi-assembly.step, openpi-parts.FCStd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]
2026-09-13 Add parametric CAD sources and layout archive
    [openpi-layout.FCStd, openpi-layout.step]
2026-09-13 Complete README, parts list and project download
    [BOM.csv]
2026-09-14 Add smaller v0.3 enclosure and hinge STL files
    [base.stl, display_bezel.stl, hinge_fixed_coupon.stl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]
2026-09-14 Add v0.3 CAD and updated fastener instructions
    [openpi-assembly.FCStd, openpi-assembly.step, openpi-parts.FCStd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]
2026-09-14 Update CAD generator for compact budget build
2026-09-14 Archive superseded v0.2 budget evidence
    [BOM-v02.csv]
2026-09-14 Add v0.3 CAD preview and HDMI wiring overview
2026-09-14 Revise OpenPi to EUR 250 planning budget v0.3
    [BOM.csv]
